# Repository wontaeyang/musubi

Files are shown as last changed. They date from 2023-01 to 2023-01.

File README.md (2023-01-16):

# Musubi - Super thin 38 key split keyboard

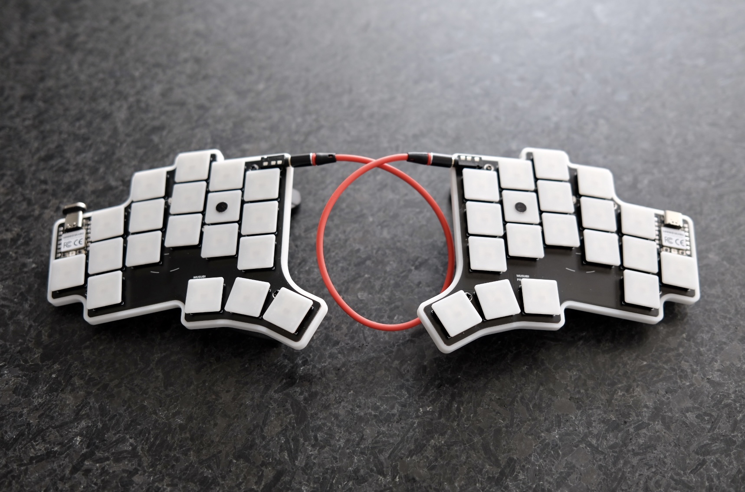
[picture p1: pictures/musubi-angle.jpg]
Musubi-angle


Musubi is a 38 key split keyboard using Kailh X switches and Seeeduino Xiao.
This keyboard started with dust keyboard as a base and adjusted with customized layout
and design elements from my favorite keyboards.

* [dust by Hazel](https://github.com/jasonhazel/dust)
* [TOTEM by GEIST](https://github.com/GEIGEIGEIST/TOTEM)
* [Dilemma by BastardKB](https://github.com/Bastardkb/Dilemma)

#### Currently there are two versions of the keyboard

* **V1** (white)
    - a lot more index and pinky column stagger
    - Totem like thumb cluster
* **V2** (red)
    - less aggressive column staggers
    - thumb cluster is extended out
    - TRRS socket location moved
    - double puck mount for wider design

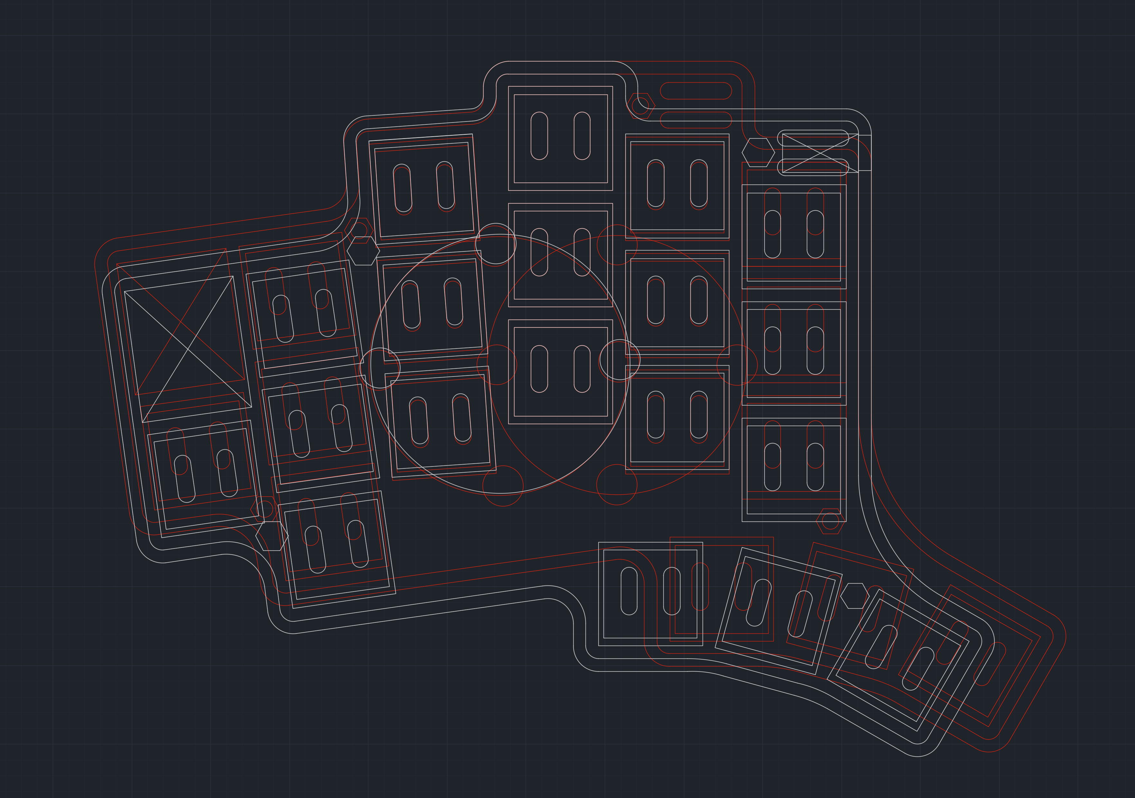
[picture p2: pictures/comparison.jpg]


# Features

* Reversible PCB
* Column stagger with splay
* 3x5 layout with 4 additional keys (three thumb, 1 pinky)
* Slim build ( measured from keycap to bottom )
    - without case 6.7 mm
    - with case 9.7 mm
* Tenting puck support

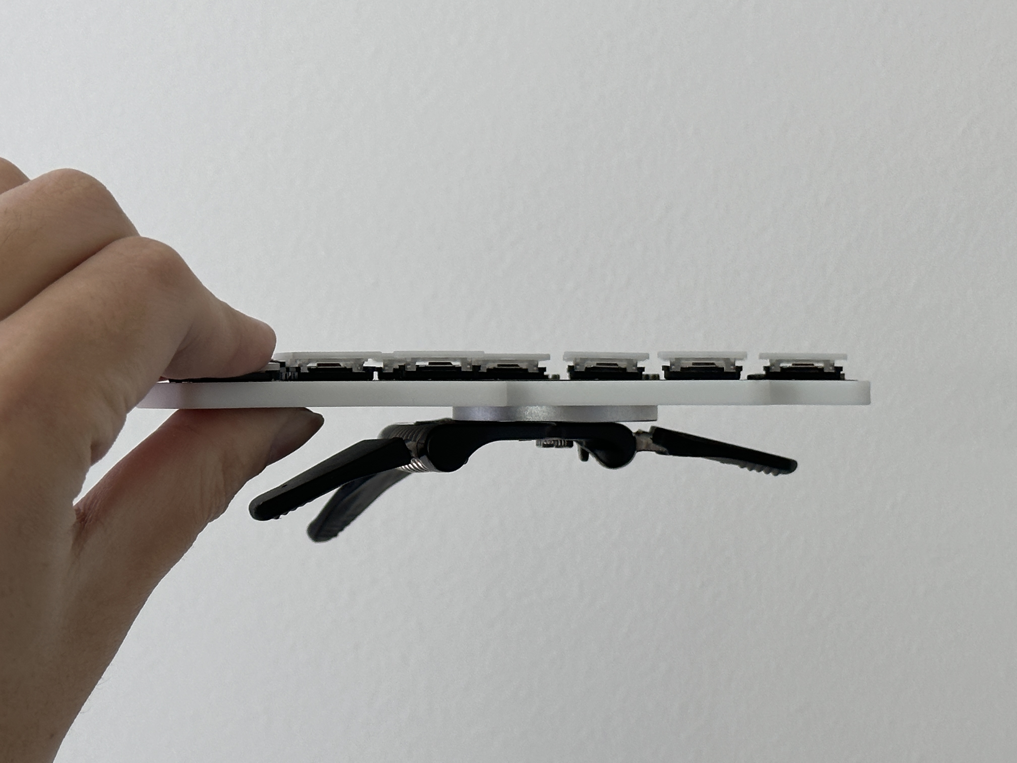
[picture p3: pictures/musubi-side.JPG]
Musubi-side


# BOM

**Base keyboard**:
* Seeeduino Xiao RP2040 (2)
* Musubi PCB (2)
* Kailh X switches (38)
* Kailh X switch keycaps (38)
* Diodes - 1N4148W  (38)
* TRRS Jack - PJ 320A 3.5mm (2)
* TRRS cable (1)

**Optional parts**:
* Musubi case (2, optional)
    - M2 4mm screw (8)
    - M2 nuts - 4mm wide, 1.6mm tall (8)
    - Tenting pucks (2, optional)
    - Manfrotto Pocket Tripod (2, optional)
    - Rubber feet (optional without tenting pucks)

# Keyboard design files

V1 files
* [V1 PCB](https://github.com/wontaeyang/musubi/blob/main/PCB/Exports/V1/musubi-pcb.zip)
* [V1 case](https://github.com/wontaeyang/musubi/tree/main/case/V1)

V2 files
* [V2 PCB](https://github.com/wontaeyang/musubi/blob/main/PCB/Exports/V2/musubi_pcb_rev2.zip)
* [V2 case](https://github.com/wontaeyang/musubi/tree/main/case/V2)

# Firmware

Musubi's firmware is a modified copy of [Dilemma's VIA keymap](https://github.com/qmk/qmk_firmware/tree/master/keyboards/bastardkb/dilemma/3x5_2/keymaps/via).
If you want to just flash the keyboard with default keymap, put the Xiaos in to bootloader mode and copy the included UF2 file

```
// For Macs
cp -X ./firmware/musubi_default.uf2 /Volumes/RPI-RP2
```

For those who wish to customize, clone this repo and symlink Musubi firmware to QMK Firmware

```
ln -s ./firmware/musubi /{your_qmk_firmware_base_location}/qmk_firmware/keyboards/musubi
```

Adjust the layout and compile/copy the UF2 file into Xiao

```
qmk compile -kb musubi -km default
cp -X ./firmware/musubi_default.uf2 /Volumes/RPI-RP2
```

# License
This work is licensed under a [Creative Commons Attribution 4.0 International License][cc-by].

[cc-by]: http://creativecommons.org/licenses/by/4.0/

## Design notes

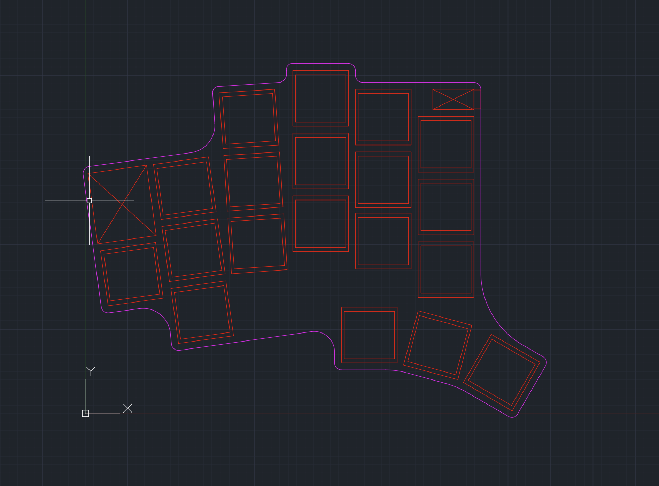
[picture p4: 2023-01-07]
pictures/autocad.png

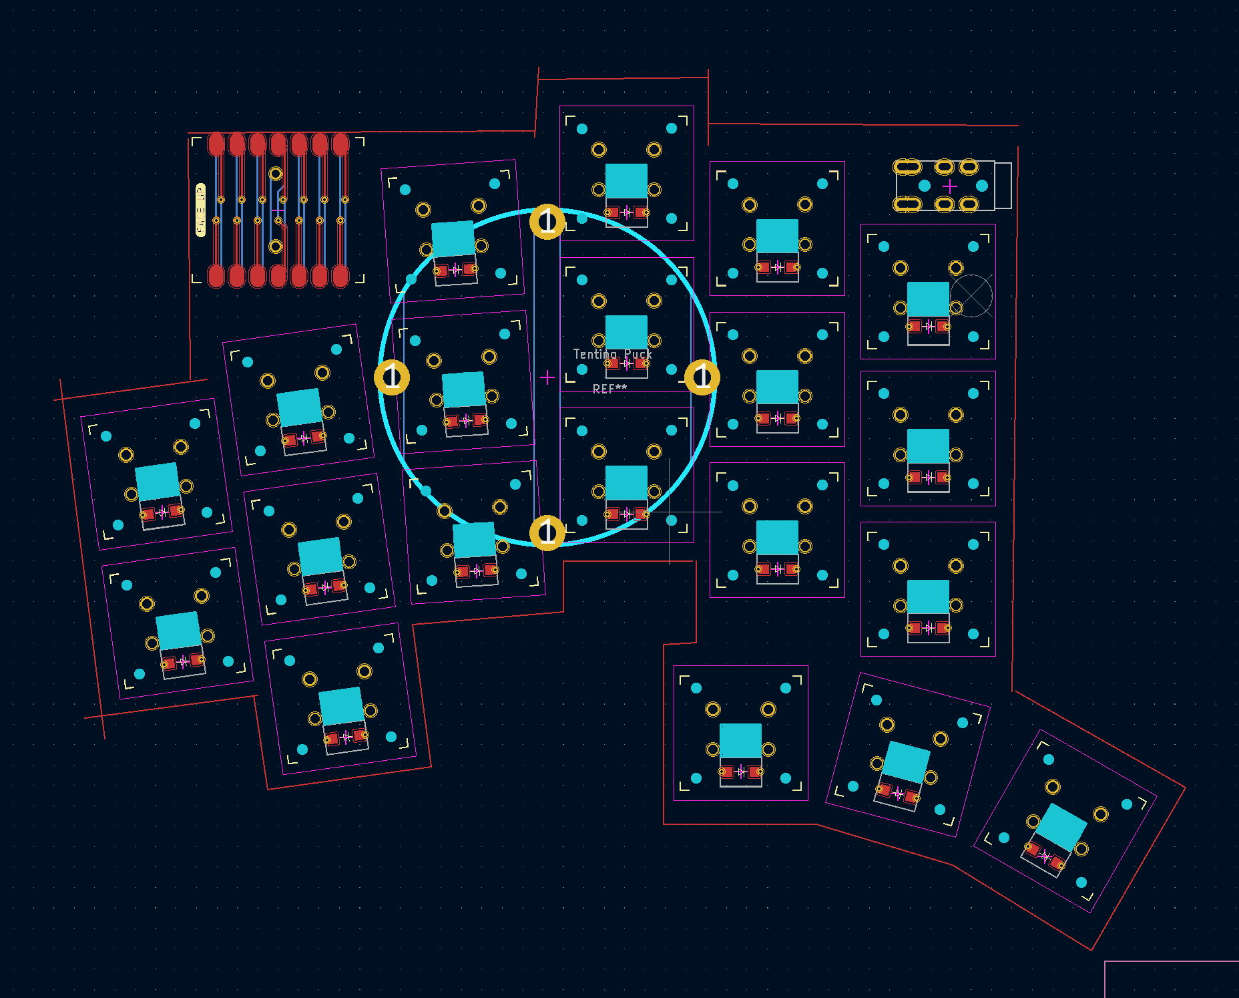
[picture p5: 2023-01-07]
pictures/sketch.png

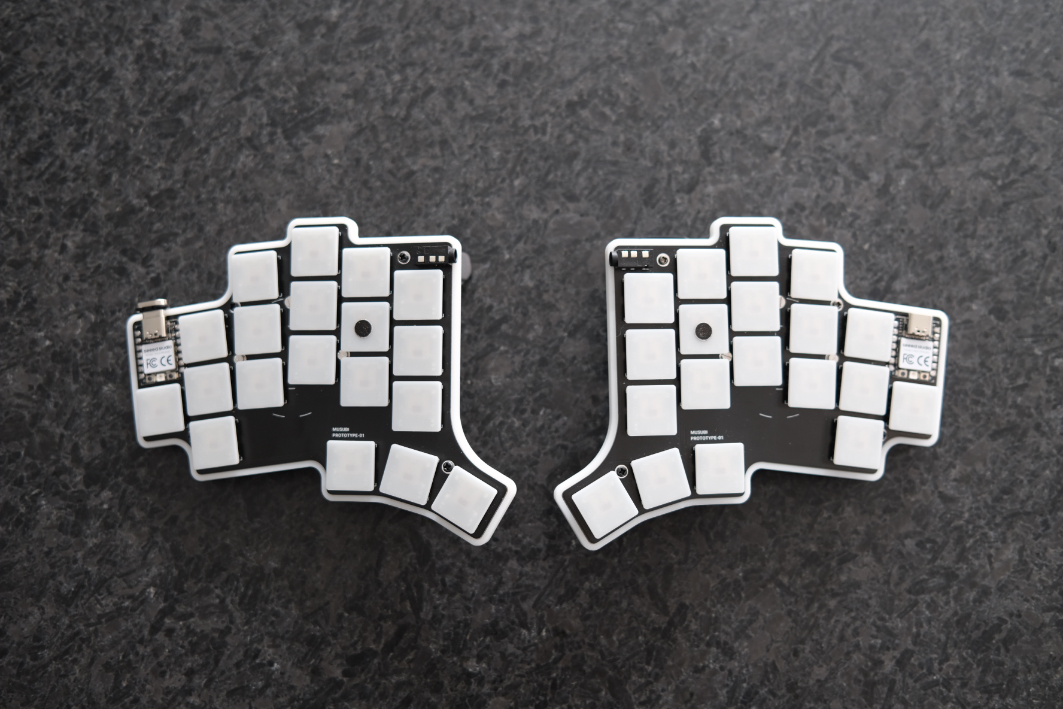
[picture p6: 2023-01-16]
pictures/musubi-top.JPG

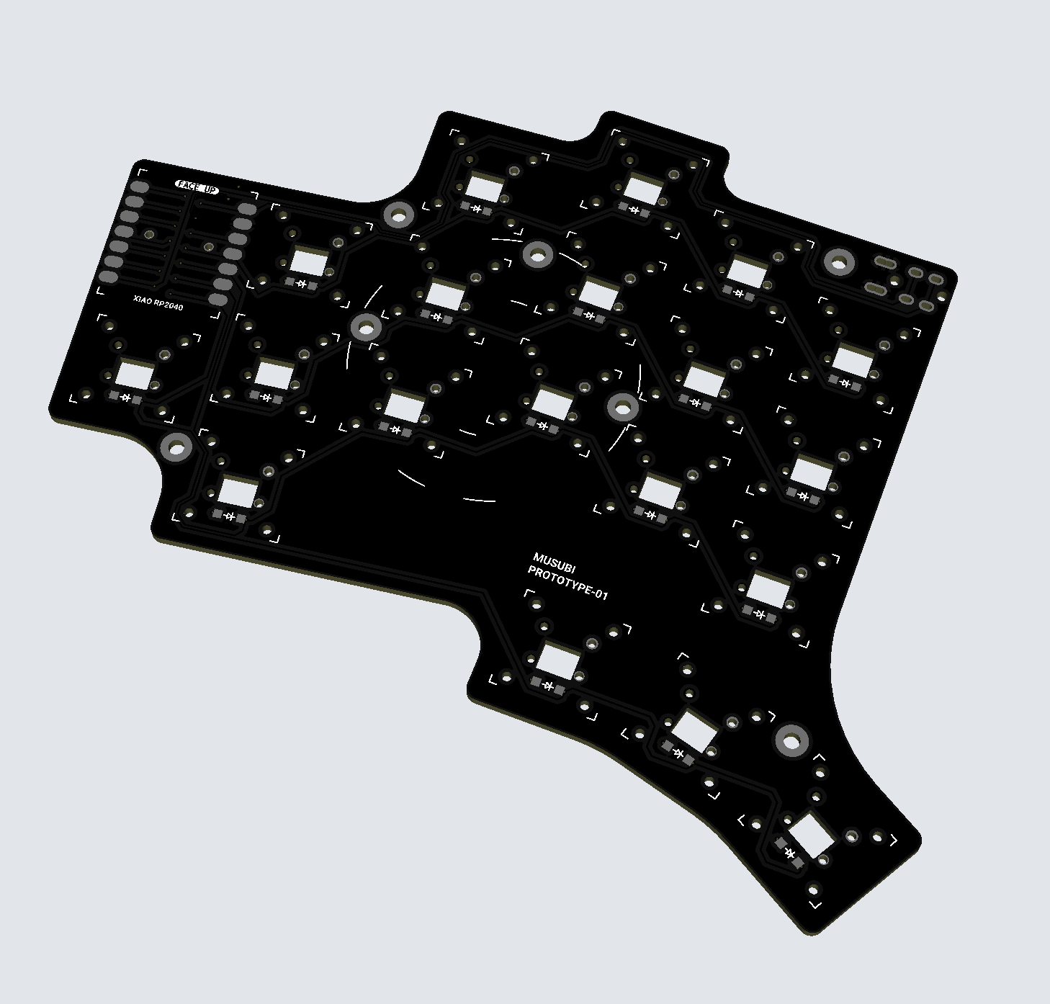
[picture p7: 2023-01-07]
pictures/pcb_preview.png

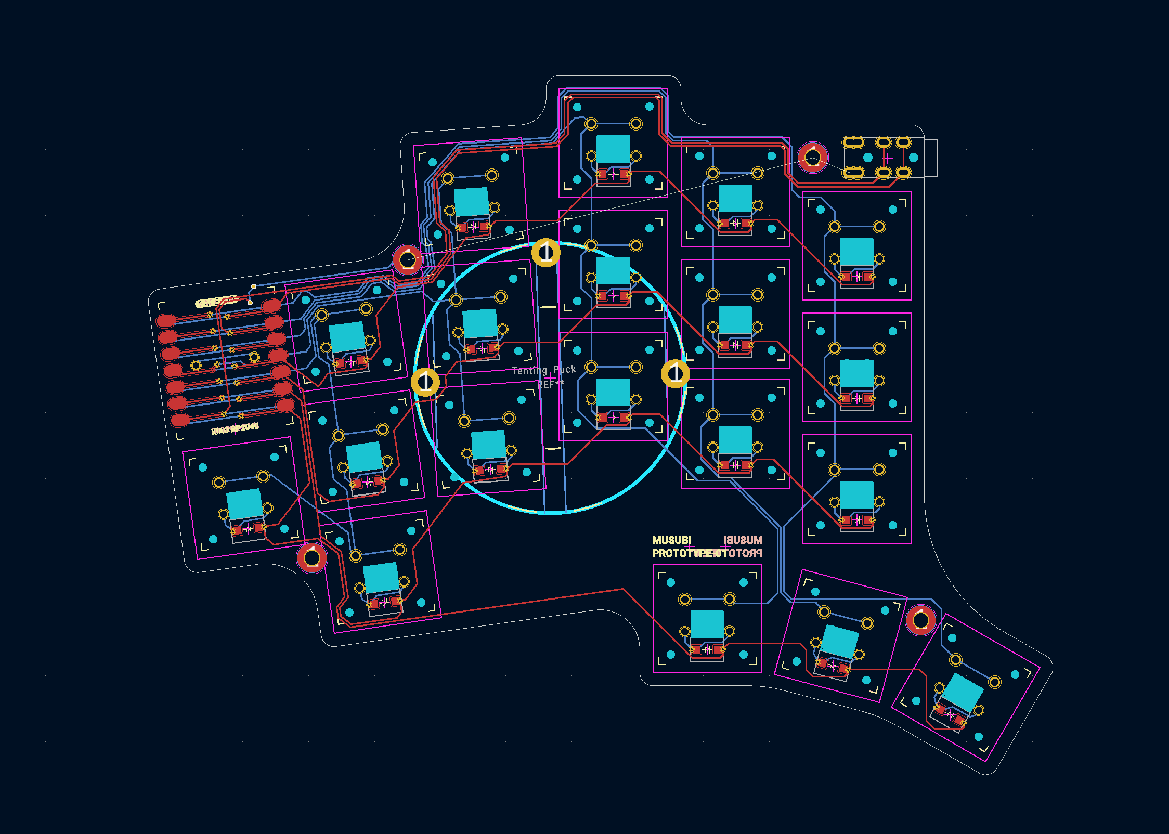
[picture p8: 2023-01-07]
pictures/kicad.png

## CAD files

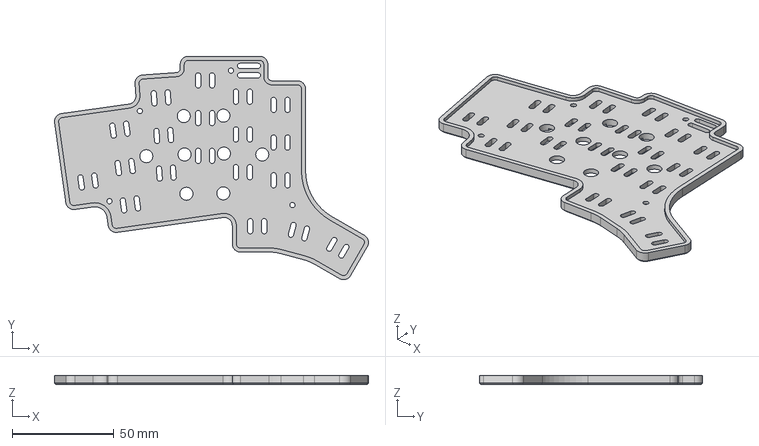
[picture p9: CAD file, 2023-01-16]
case/V2/perforated/MUSUBI_V2_CASE_LEFT.step
154.0 x 109.5 x 4.60 mm

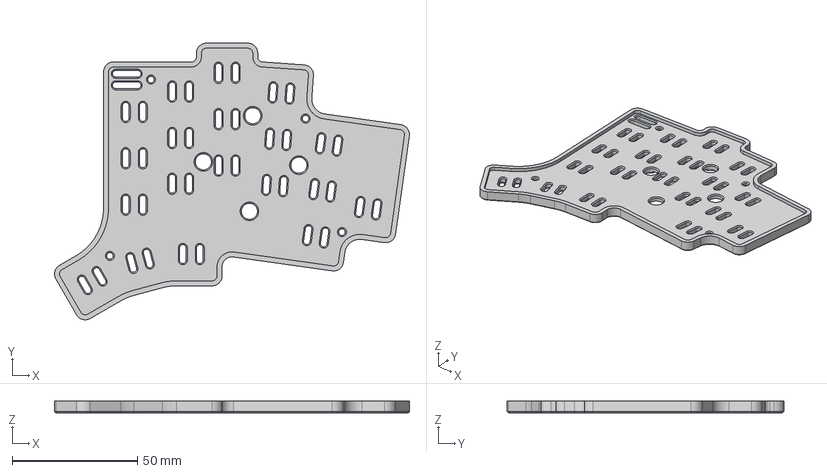
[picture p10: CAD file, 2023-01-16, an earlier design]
case/V1/perforated/MUSUBI_V1_CASE_RIGHT.step
141.5 x 110.3 x 4.60 mm

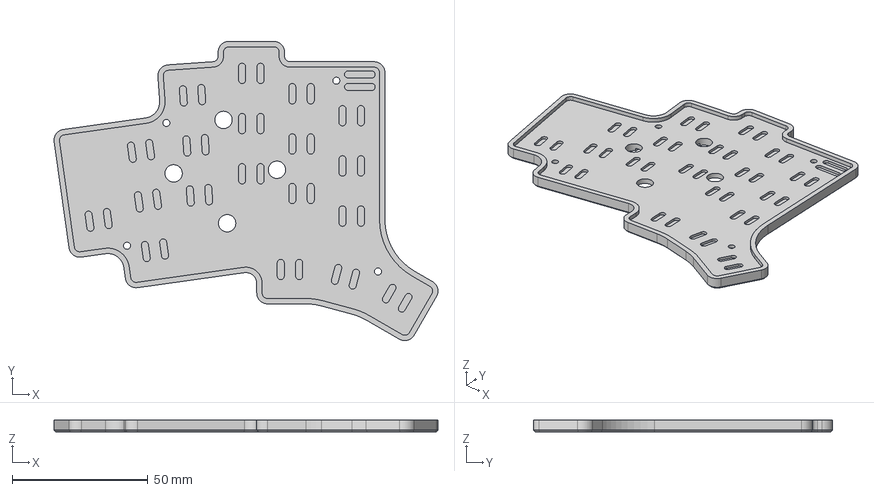
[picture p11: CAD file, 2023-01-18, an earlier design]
case/V1/solid/MUSUBI_V1_CASE_SOLID_LEFT.step
141.5 x 110.3 x 4.60 mm

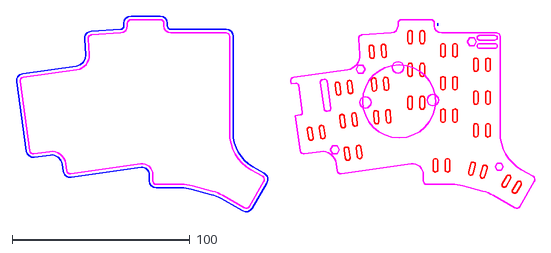
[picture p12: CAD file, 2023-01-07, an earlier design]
dxf/WIP_case.dxf
292.2 x 110.9

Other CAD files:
case/V2/solid/MUSUBI_V2_CASE_SOLID_RIGHT.step
dxf/WIP_rev2_case.dxf
case/V2/perforated/MUSUBI_V2_CASE_RIGHT.step
case/V2/solid/MUSUBI_V2_CASE_SOLID_LEFT.step
dxf/WIP_rev2.dxf
dxf/WIP_case_rev2.dwg
dxf/WIP_case_bottom.dxf
dxf/WIP_exploded.dxf
case/V1/perforated/MUSUBI_V1_CASE_LEFT.step
case/V1/solid/MUSUBI_V1_CASE_SOLID_RIGHT.step
dxf/WIP.dxf
case/V1/perforated/MUSUBI_V1_CASE.f3d
case/V1/solid/MUSUBI_V1_CASE_SOLID.f3d
case/V2/perforated/MUSUBI_V2_CASE.f3d
case/V2/solid/MUSUBI_V2_CASE_SOLID.f3d
dxf/WIP.dwg
dxf/WIP_case.dwg
dxf/WIP_case_bottom.dwg
dxf/WIP_exploded.dwg
dxf/WIP_rev2.dwg

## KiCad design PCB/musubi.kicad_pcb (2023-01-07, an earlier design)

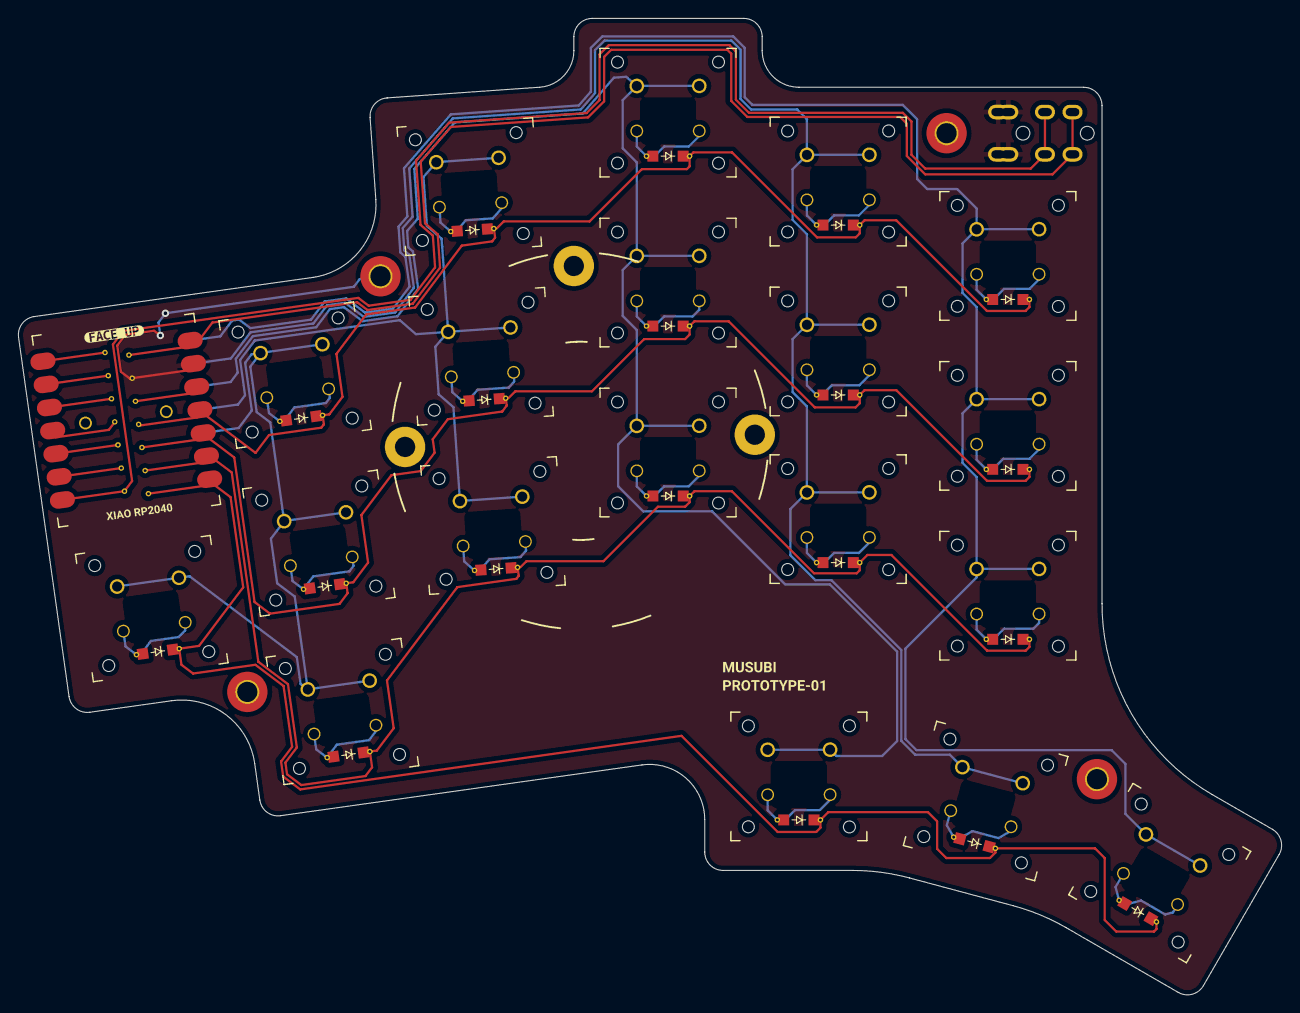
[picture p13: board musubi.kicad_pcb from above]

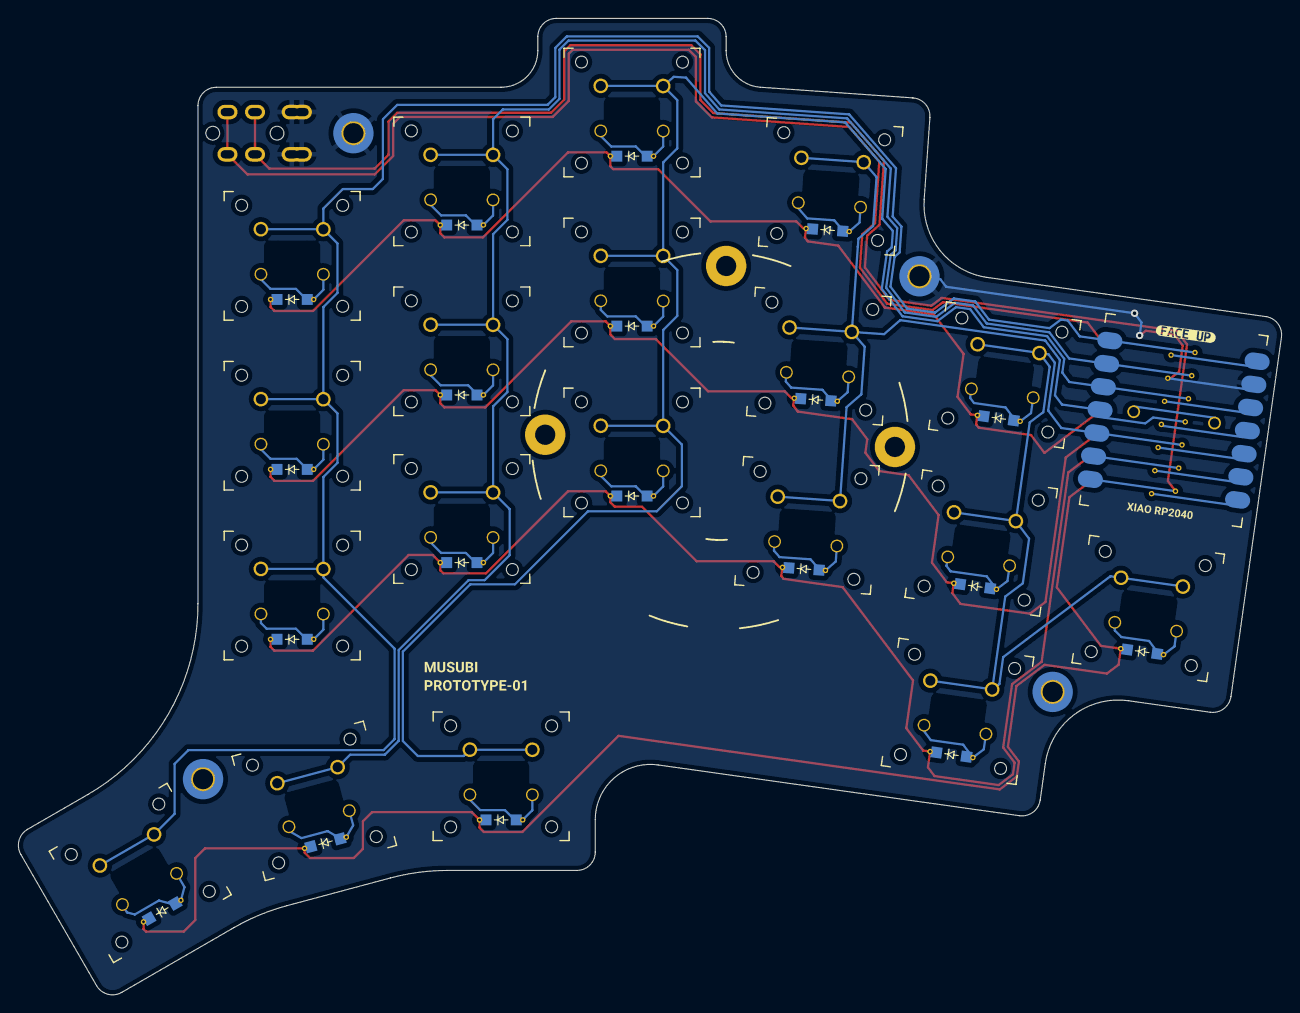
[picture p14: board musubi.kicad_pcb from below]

Board: 2 copper layers, 137.5 x 106.3 mm, 44 parts (2 on the bottom side), 31 nets.

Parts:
D1, D2, D3, D4, D5, D6, D7, D8, D9, D10, D11, D12, D13, D14, D15, D17, D18, D19, D20: D_Small; diode-reversible
J1: AudioJack4; TRRS-PJ-320A-dual
SW1, SW2, SW3, SW4, SW5, SW6, SW7, SW8, SW9, SW10, SW11, SW12, SW13, SW14, SW15, SW17, SW18, SW19, SW20: SW_Push_45deg; Kailh-PG1425-X-Switch-revers
U1: xiao-ble; xiao-rev-reversible
kibuzzard-63ADF2C0, kibuzzard-63ADF2C0#2: G***; kibuzzard-63ADF2C0
kibuzzard-63ADF196, kibuzzard-63ADF196#2: G***; kibuzzard-63ADF196

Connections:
COL0: SW1.1, SW6.1, SW11.1, SW17.1, U1.5 (A8_SDA/0.04_H)
COL1: SW2.1, SW7.1, SW12.1, U1.4 (A11/0.29)
COL2: SW3.1, SW8.1, SW13.1, SW18.1, U1.3 (A10/0.28)
COL3: SW4.1, SW9.1, SW14.1, SW19.1, U1.2 (A4/0.03_H)
COL4: SW5.1, SW10.1, SW15.1, SW20.1, U1.1 (A2/0.02_H)
GND: J1.1, J1.2, U1.13 (GND)
unnamed: D1.2 (A), SW1.2
unnamed: D2.2 (A), SW2.2
unnamed: D3.2 (A), SW3.2
unnamed: D4.2 (A), SW4.2
unnamed: D5.2 (A), SW5.2
unnamed: D6.2 (A), SW6.2
unnamed: D7.2 (A), SW7.2
unnamed: D8.2 (A), SW8.2
unnamed: D9.2 (A), SW9.2
unnamed: D10.2 (A), SW10.2
unnamed: D11.2 (A), SW11.2
unnamed: D12.2 (A), SW12.2
unnamed: D13.2 (A), SW13.2
unnamed: D14.2 (A), SW14.2
unnamed: D15.2 (A), SW15.2
unnamed: D17.2 (A), SW17.2
unnamed: D18.2 (A), SW18.2
unnamed: D19.2 (A), SW19.2
unnamed: D20.2 (A), SW20.2
ROW0: D1.1 (K), D2.1 (K), D3.1 (K), D4.1 (K), D5.1 (K), U1.11 (A6_MOSI/1.15)
ROW1: D6.1 (K), D7.1 (K), D8.1 (K), D9.1 (K), D10.1 (K), U1.10 (A5_MISO/1.14)
ROW2: D11.1 (K), D12.1 (K), D13.1 (K), D14.1 (K), D15.1 (K), U1.9 (A7_SCK/1.13)
ROW3: D17.1 (K), D18.1 (K), D19.1 (K), D20.1 (K), U1.8 (B9_RX/1.12)
TX: J1.3, U1.7 (B8_TX/1.11)
VCC: J1.4, U1.14 (5V)

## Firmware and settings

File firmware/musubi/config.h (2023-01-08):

#pragma once

#include "config_common.h"

#define MATRIX_COLS   5
#define MATRIX_ROWS   8

#define DIODE_DIRECTION COL2ROW
#define MATRIX_ROW_PINS { GP3, GP4, GP2, GP1 }
#define MATRIX_COL_PINS { GP6, GP29, GP28, GP27, GP26 }

#define SOFT_SERIAL_PIN GP0
#define USE_SERIAL
#define SELECT_SOFT_SERIAL_SPEED 0

#define EE_HANDS

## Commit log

2023-01-07 Add BOM
2023-01-14 Add reverse thumb layout
    [config.h]
2023-01-16 Lots of stuff
    [MUSUBI_CASE.f3d, MUSUBI_CASE_RIGHT_rev2.step, MUSUBI_V1_CASE_LEFT.step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]
2023-01-16 Rename pcb exports
    [musubi-B_Cu.gbl, musubi-B_Mask.gbs, musubi-B_Paste.gbp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]
2023-01-18 Reorganize cases
    [MUSUBI_V1_CASE_LEFT.step, MUSUBI_V2_CASE.f3d, MUSUBI_V2_CASE_LEFT.step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]
2023-01-18 Remove extra file
    [MUSUBI_V2_CASE_SOLID.step]
2023-01-18 Fix cases
    [MUSUBI_V1_CASE.f3d, MUSUBI_V1_CASE_RIGHT.step, MUSUBI_V1_CASE_SOLID.f3d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]
